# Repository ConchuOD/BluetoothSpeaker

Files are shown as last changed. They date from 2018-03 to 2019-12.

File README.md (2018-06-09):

# Teensy Bluetooth Speaker           
This repo houses the hardware and code for a bluetooth speaker. It uses an [RN52 from Roving Networks](https://www.microchip.com/wwwproducts/en/RN52) on one daughterboard to provide the bluetooth streaming capabilities and a [Teensy3.2 from PJRC](https://www.pjrc.com/store/teensy32.html) on another to control operation and power a [touchscreen display](https://www.pjrc.com/store/display_ili9341_touch.html) which displays the song metadata as well as houses AVRCP buttons.
The amplification is provided by a [TI 20 Watt Class-D amplifier](http://www.ti.com/lit/ds/symlink/tpa3140d2.pdf). Power comes from a 3S LiPo battery I had lying around from a RC project, with the amp being powered from 10.5 volts & seperate 3.3V rail for the RN52/Teensy/Display.

The V1 board only worked after a number of modifications were made. These modifications were echoed in V2 which also introduced the display. A V3 is planned which will place the RN52 directly on the board itself. As the RN52 is relatively expensive the V1/V2 boards were created with the option to use a cheap Chinese A2DP module which required swapping the ADP2370 for an adjustable version as well as inserting some zero Ohm links. An approximate BOM is included as a spreadsheet, however the pricing in the first section is all rather approximate.

*>insert photos of display, board & enclosure when complete*

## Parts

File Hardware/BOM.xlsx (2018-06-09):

Item | Part Name | Acq.? | Farnell ID | Farnell Cost | Digikey ID | Digikey Cost | OSH Park ID | OSH Park Cost | AliExpress Link | AliExpress Cost | Other ID | Other Cost | Quantity | Total Cost
Main parts
RN52 | RN52-I/RM116 | ✓ | 2491389 | €17.50 |  |  |  |  |  |  |  |  | 1 | €17.50
RN52 Shenzen | BLK-MD-SPK-B |  |  |  |  |  |  |  |  | €5.00
HC05 | HC-05 | ✓ |  |  |  |  |  |  |  | €2.95 |  |  | 1 | €2.95
T3.2 | Teensy 3.2 | ✓ |  |  |  |  |  |  |  |  | T3.2 | €19.75 | 1 | €19.75
TFT | PJRC TFT | ✓ |  |  |  |  |  |  |  |  | TFT | €10.00 | 1 | €10.00
Audio PA | TPA3140D2PWP | ✓ | 2483133 | €3.93 |  |  |  |  |  |  |  |  | 1 | €3.93
Buck Converter | ADP2370 | ✓ | 2727509 | €3.80 |  |  |  |  |  |  |  |  | 1 | €3.80
LDR | NCP59302DSADJR4G | ✓ | 2464250 | €2.81 |  |  |  |  |  |  |  |  | 1 | €2.81
RN52 BoB | n/a | ✓ |  |  |  |  | RN52BoB | $4.50 |  |  |  |  | 1 | €5.00
Main PCB | n/a | ✓ |  |  |  |  |  |  |  |  |  |  | 1 | €5.00
Enclosure |  |  |  |  |  |  |  |  | Enclosure 7.87" X 4.72" X 2.95" |  |  |  | 1 | €5.00
Li-Po Battery | ZIPPY Compact 5800mAh 3S 25C | ✓ |  |  |  |  |  |  |  |  |  | €38.00
XT-60 Female |  | ✓ |  |  |  |  |  |  |  |  | XT-60 F | ?
Speakers | Aiyima 2Pcs 8 Ohm 10W | ✓ |  |  |  |  |  |  |  | €12.60 | *hopefully* | €5.00 | 2 | €25.20 | €100.94 | €53.49
RN52 Hookup
Green LED 0603 | SML-D12P8WT86C | ✓ | 2687486 | €0.45 |  |  |  |  |  |  |  |  | 1 | €0.45
Red LED 0603 | SML-D12V8WT86C | ✓ | 2687488 | €0.45 |  |  |  |  |  |  |  |  | 1 | €0.45
330R 0603 | CRGS0603J330R | ✓ | 2531684 | €0.14 |  |  |  |  |  |  |  |  | 2 | €0.28
20 pin 0.1" Header Male | M20-9992046 | ✓ | 1022262 | €0.41 |  |  |  |  |  |  |  |  | 2 | €0.82
20 pin 0.1" Header Female | 2212S-20SG-85 | ✓ | 1593469 | €0.75 |  |  |  |  |  |  |  |  | 2 | €1.50 | €3.49
PA Hookup
100 uF Radial Can | EEEFK1C101P | ✓ | 9695672 | €0.28 |  |  |  |  |  |  |  |  | 1 | €0.28
1 uF 0603 | MC0603X105K100CT | ✓ | 1759399 | €0.23 |  |  |  |  |  |  |  |  | 10 | €2.29
220 nF 0603 | MC0603B224K160CT | ✓ | 2627437 | €0.03 |  |  |  |  |  |  |  |  | 4
100 nF 0603 | MCT0603F104ZCT | ✓ | 9406204 | €0.01 |  |  |  |  |  |  |  |  | 1
1 nF 0603 | MC0603B102K250CT | ✓ | 2627426 | €0.01 |  |  |  |  |  |  |  |  | 5
Ferrite Bead | 742792031 | ✓ | 1635734 | €0.26 |  |  |  |  |  |  |  |  | 4 | €1.04
10R 0603 | CRCW060310R0JNEAHP | ✓ | 2614306 | €0.15 |  |  |  |  |  |  |  |  | 1
39k 0603 | CRGS0603J39K | ✓ | 2531713 | €0.14 |  |  |  |  |  |  |  |  | 1
33k 0603 | CRGS0603J33K | ✓ | 2531712 | €0.14 |  |  |  |  |  |  |  |  | 3
56k 0603 | CRGS0603J56K | ✓ | 2531715 | €0.14 |  |  |  |  |  |  |  |  | 1
2 Hole Terminal Block | 1776275-2 | ✓ | 1098611 | €0.24 |  |  |  |  |  |  |  |  | 2 | €0.48 | €4.09
LDO Hookup
100 uF Radial Can | EEEFK1C101P | ✓ | 9695672 | €0.28 |  |  |  |  |  |  |  |  | 1 | €0.28
10 nF 0603 X5R | C1005X5R1E103K050BA | ✓ | 2525020 | €0.05 |  |  |  |  |  |  |  |  | 1 | €0.05
360k 0603 | ERJPA3F3603V | ✓ | 2335905 | €0.09 |  |  |  |  |  |  |  |  | 1
48k 0603 | CRGS0603J47K | ✓ | 2531714 | €0.14 |  |  |  |  |  |  |  |  | 1 |  | €0.33
Buck Conv. Hookup
10 uF 1206 X5R (output) | C1206C106K4PACTU | ✓ | 9227881 | €0.19 |  |  |  |  |  |  |  |  | 2 | €0.38
10 uF 1206 X5R (input) | MC1206X106K250CT | ✓ | 2320887 | €0.21 |  |  |  |  |  |  |  |  | 1 | €0.21
10 uH | SRN3015-100M | ✓ | 2061634 | €0.32 |  |  |  |  |  |  |  |  | 1 | €0.32
10k 0603 | CRGS0603J10K | ✓ | 2531704 | €0.14 |  |  |  |  |  |  |  |  | 1
33k 0603 | CRGS0603J33K | ✓ | 2531712 | €0.14 |  |  |  |  |  |  |  |  | 1
56K 0603 | CRGS0603J56K | ✓ | 2531715 | €0.14 |  |  |  |  |  |  |  |  | 1
68k 0603 | CRGS0603J68K | ✓ | 2531716 | €0.14 |  |  |  |  |  |  |  |  | 1
200k 0603 | ERJPA3F2053V | ✓ | 2561864 | €0.16 |  |  |  |  |  |  |  |  | 1 |  | €0.91
T3.2 Hookup
14 Pin 0.1" Header Female | 2212S-14SG-85 | ✓ | 1593466 | €0.51 |  |  |  |  |  |  |  |  | 2 | €1.02
14 Pin 0.1" Header Male | MC34735 | ✓ | 1593421 | €0.15 |  |  |  |  |  |  | PJRC | €0.85 | 2 | €1.70 | €1.70
 | HC05 Hookup
6 Pin 90degree Header | Need spacing info after delivery | ** | ** | ** | ** | ** | ** | ** | ** | ** | ** | ** | 1 | €1.50 | €1.50
 |  |  |  |  |  |  |  |  |  |  |  |  |  |  | €112.97 | €65.52

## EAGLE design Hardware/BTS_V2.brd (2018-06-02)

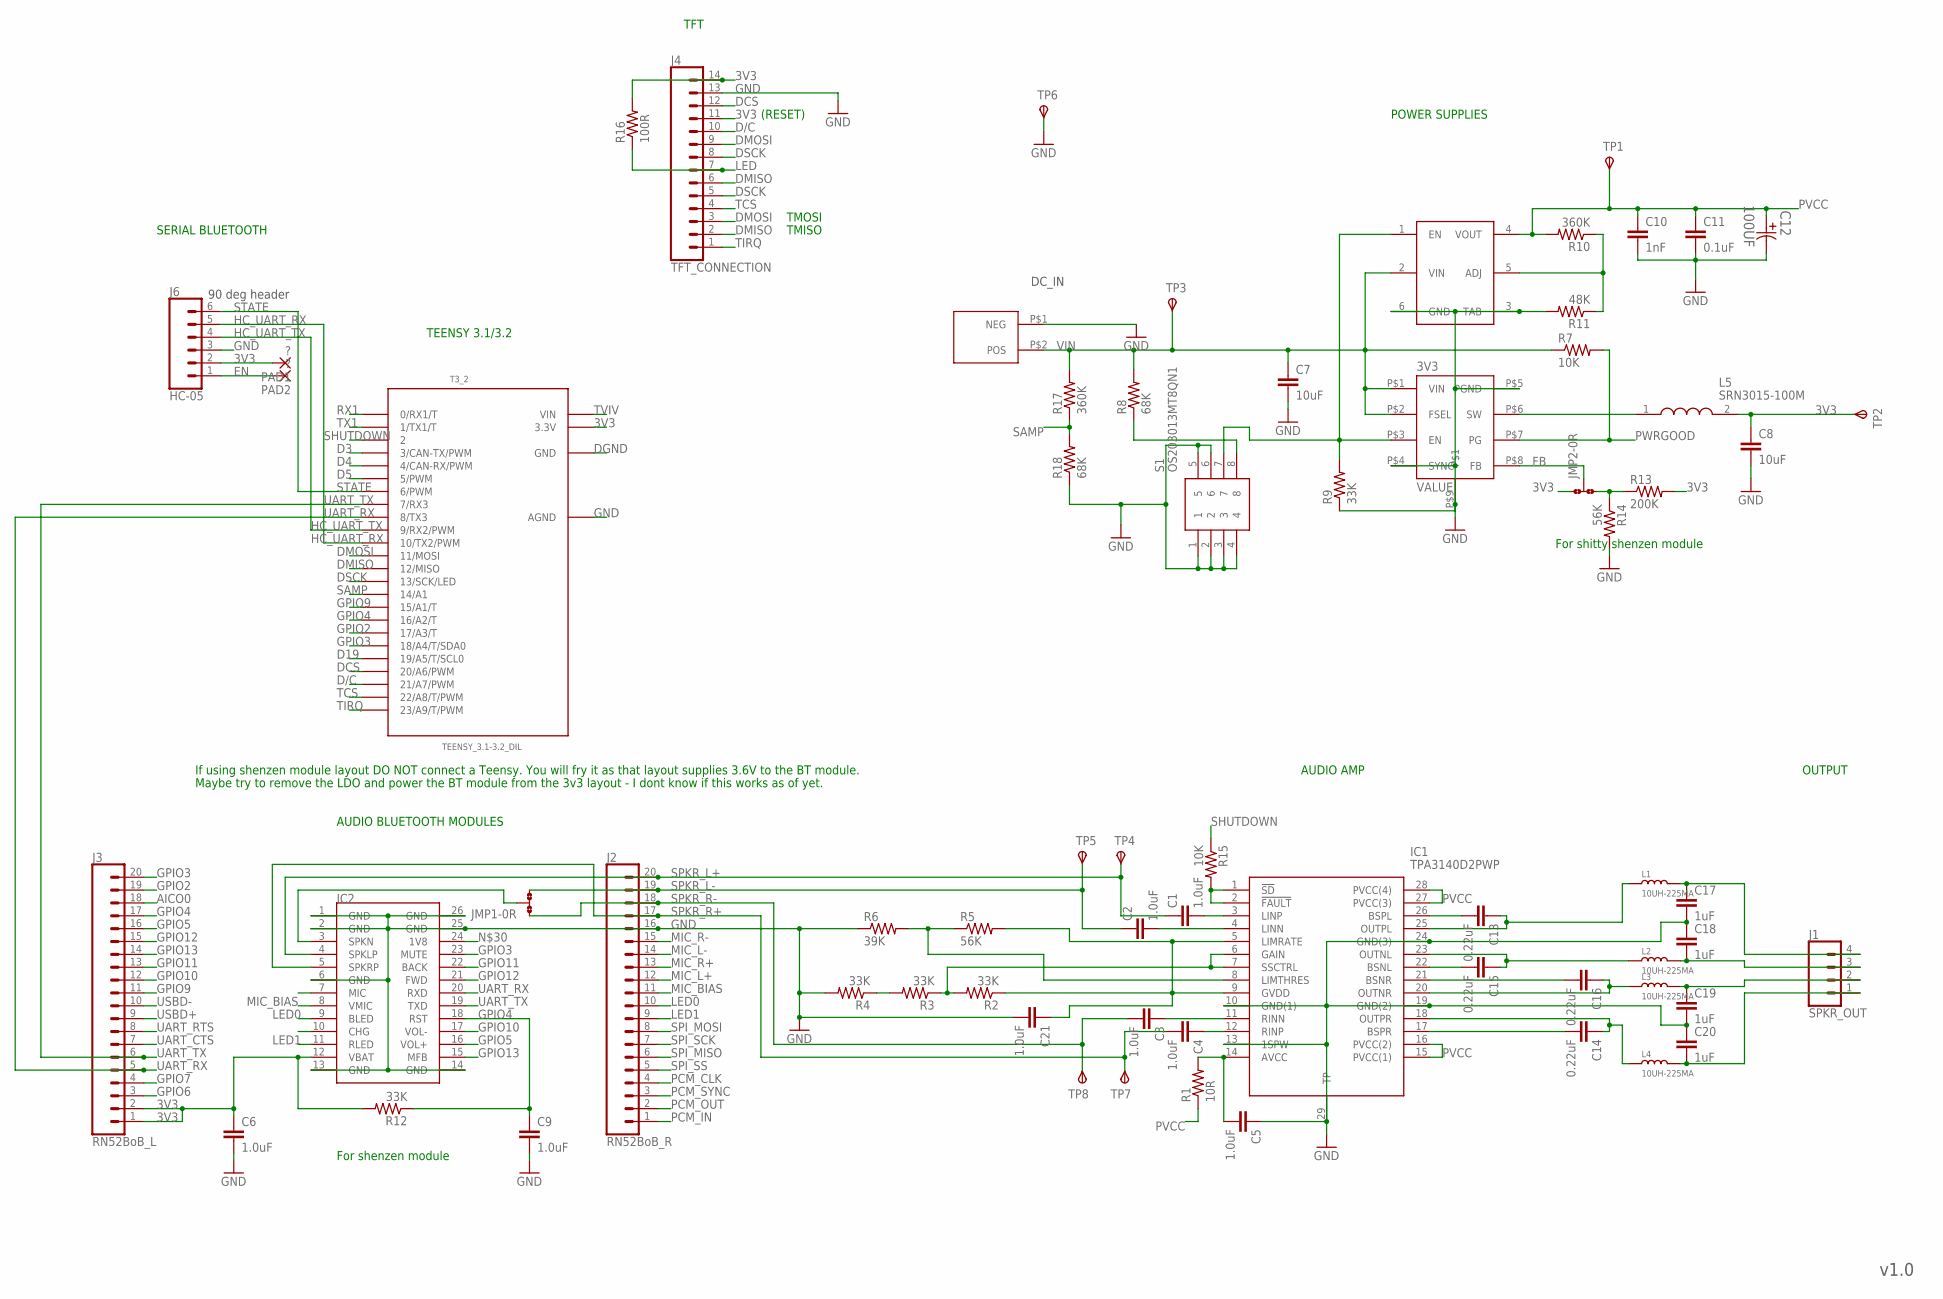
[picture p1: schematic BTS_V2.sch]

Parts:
3V3: ADP2370; 3MM_LFCSP_QFN
C1, C2, C3, C4, C5, C6, C9, C21: 1.0uF; 0603
C7, C8: 10uF; C3216
C10: 1nF; 0603
C11: 0.1uF; 0603
C12: 100UF; CAPAE660X610N
C13, C14, C15, C16: 0.22uF; 0603
C17, C18, C19, C20: 1uF; 0603
IC1: TPA3140D2PWP; SOP65P640X120-29N
IC2: BLK-MD-SPK-B
J1: SPKR_OUT; SCREWTERMINAL-3.5MM-4
J2: RN52BoB_R; 1X20
J3: RN52BoB_L; 1X20
J4: TFT_CONNECTION; 1X14
J6: HC-05; 1X06
JMP1, JMP2: 0R-JUMPA; A0R-JMP
L1, L2, L3, L4: 10UH-225MA; L0806
L5: SRN3015-100M; SRN3015
PAD1, PAD2: ?; SMD1,27-2,54
R1: 10R; R0603
R2, R3, R4, R9, R12: 33K; R0603
R5, R14: 56K; R0603
R6: 39K; R0603
R7, R15: 10K; R0603
R8, R18: 68K; R0603
R10, R17: 360K; R0603
R11: 48K; R0603
R13: 200K; R0603
R16: 100R; R0603
S1: OS203013MT8QN1
T3_2: TEENSY_3.1-3.2_DIL; TEENSY_3.0-3.2&LC_DIL
TP1, TP2, TP3, TP4, TP5, TP6, TP7, TP8: TPSPAD1-17; P1-17
U$1: HK_XT-60; HOBBYKING_XT-60
U$2: NCP59302; D2PAK-5

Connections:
3V3: C6.1, C8.1, IC2.12 (VBAT), J3.1, J3.2, J4.11, J4.14, J6.2, JMP2.1, L5.2, PAD1.1, R12.2, R13.2, R16.2, T3_2.3.3V, TP2.TP
AICO0: J3.18
BSNL: C15.2, IC1.22 (BSNL)
BSNR: C16.2, IC1.21 (BSNR)
BSPL: C13.2, IC1.26 (BSPL)
BSPR: C14.2, IC1.17 (BSPR)
D3: T3_2.3 (3/CAN-TX/PWM)
D4: T3_2.4 (4/CAN-RX/PWM)
D5: T3_2.5 (5/PWM)
D19: T3_2.19/A5 (19/A5/T/SCL0)
D/C: J4.10, T3_2.21/A7 (21/A7/PWM)
DCS: J4.12, T3_2.20/A6 (20/A6/PWM)
DGND: T3_2.GND
DMISO: J4.2, J4.6, T3_2.12 (12/MISO)
DMOSI: J4.3, J4.9, T3_2.11 (11/MOSI)
DSCK: J4.5, J4.8, T3_2.13 (13/SCK/LED)
EN: J6.1, PAD2.1
FB: 3V3.P$8 (FB), JMP2.2
GAIN: IC1.6 (GAIN), IC1.7 (SSCTRL), R2.2, R3.1
GND: 3V3.P$4 (SYNC), 3V3.P$5 (PGND), 3V3.P$9, C5.1, C6.2, C7.2, C8.2, C9.2, C10.2, C11.2, C12.2, C17.2, C18.1, C19.2, C20.1, C21.2, IC1.10 (GND(1)), IC1.13 (1SPW), IC1.19 (GND(2)), IC1.24 (GND(3)), IC1.29 (TP), IC2.1 (GND), IC2.2 (GND), IC2.6 (GND), IC2.13 (GND), IC2.14 (GND), IC2.25 (GND), IC2.26 (GND), J2.16, J4.13, J6.3, R4.2, R6.1, R9.1, R11.2, R14.2, R18.1, S1.1, S1.2, S1.3, S1.4, S1.5, S1.6, T3_2.AGND, TP6.TP, U$1.P$1 (NEG), U$2.3 (TAB), U$2.6 (GND)
GPIO2: J3.19, T3_2.17/A3 (17/A3/T)
GPIO3: IC2.23 (MUTE), J3.20, T3_2.18/A4 (18/A4/T/SDA0)
GPIO4: C9.1, IC2.18 (RST), J3.17, R12.1, T3_2.16/A2 (16/A2/T)
GPIO5: IC2.16 (VOL+), J3.16
GPIO6: J3.3
GPIO7: J3.4
GPIO9: J3.11, T3_2.15/A1 (15/A1/T)
GPIO10: IC2.17 (VOL-), J3.12
GPIO11: IC2.22 (BACK), J3.13
GPIO12: IC2.21 (FWD), J3.15
GPIO13: IC2.15 (MFB), J3.14
GVDD: C21.1, IC1.5 (LIMRATE), IC1.9 (GVDD), R2.1, R5.2
HC_UART_RX: J6.5, T3_2.10 (10/TX2/PWM)
HC_UART_TX: J6.4, T3_2.9 (9/RX2/PWM)
LED: J4.7, R16.1
LED0: IC2.9 (BLED), J2.10
LED1: IC2.11 (RLED), J2.9
LIMTHRES: IC1.8 (LIMTHRES), R5.1, R6.2
LINN: C2.2, IC1.4 (LINN)
LINP: C1.2, IC1.3 (LINP)
MIC_BIAS: IC2.8 (VMIC), J2.11
MIC_L+: J2.12
MIC_L-: J2.14
MIC_R+: J2.13
MIC_R-: J2.15
unnamed: C5.2, IC1.14 (AVCC), R1.2
unnamed: IC1.1 (!SD), IC1.2 (!FAULT), R15.2
unnamed: R3.2, R4.1
unnamed: C17.1, J1.4, L1.2
unnamed: C18.2, J1.3, L2.2
unnamed: C19.1, J1.2, L3.2
unnamed: C20.2, J1.1, L4.2
unnamed: JMP2.3, R13.1, R14.1
unnamed: IC2.3 (SPKN), JMP1.2
unnamed: 3V3.P$3 (EN), R9.2, S1.7, U$2.1 (EN)
unnamed: 3V3.P$6 (SW), L5.1
unnamed: R8.1, S1.8
unnamed: R10.1, R11.1, U$2.5 (ADJ)
OUTNL: C15.1, IC1.23 (OUTNL), L2.1
OUTNR: C16.1, IC1.20 (OUTNR), L3.1
OUTPL: C13.1, IC1.25 (OUTPL), L1.1
OUTPR: C14.1, IC1.18 (OUTPR), L4.1
PCM_CLK: J2.4
PCM_IN: J2.1
PCM_OUT: J2.2
PCM_SYNC: J2.3
PVCC: C10.1, C11.1, C12.1, IC1.15 (PVCC(1)), IC1.16 (PVCC(2)), IC1.27 (PVCC(3)), IC1.28 (PVCC(4)), R1.1, R10.2, TP1.TP, U$2.4 (VOUT)
PWRGOOD: 3V3.P$7 (PG), R7.2
RINN: C3.1, IC1.11 (RINN)
RINP: C4.1, IC1.12 (RINP)
RX1: T3_2.0 (0/RX1/T)
SAMP: R17.1, R18.2, T3_2.14/A0 (14/A1)
SHUTDOWN: R15.1, T3_2.2
SPI_MISO: J2.6
SPI_MOSI: J2.8
SPI_SCK: J2.7
SPI_SS: J2.5
SPKR_L+: C1.1, IC2.4 (SPKLP), J2.20, TP4.TP
SPKR_L-: C2.1, J2.19, JMP1.3, TP5.TP
SPKR_R+: C4.2, IC2.5 (SPKRP), J2.17, TP7.TP
SPKR_R-: C3.2, J2.18, JMP1.1, TP8.TP
STATE: J6.6, T3_2.6 (6/PWM)
TCS: J4.4, T3_2.22/A8 (22/A8/T/PWM)
TIRQ: J4.1, T3_2.23/A9 (23/A9/T/PWM)
TVIV: T3_2.VIN
TX1: T3_2.1 (1/TX1/T)
UART_CTS: J3.7
UART_RTS: J3.8
UART_RX: IC2.20 (RXD), J3.5, T3_2.8 (8/TX3)
UART_TX: IC2.19 (TXD), J3.6, T3_2.7 (7/RX3)
USBD+: J3.9
USBD-: J3.10
VIN: 3V3.P$1 (VIN), 3V3.P$2 (FSEL), C7.1, R7.1, R8.2, R17.2, TP3.TP, U$1.P$2 (POS), U$2.2 (VIN)

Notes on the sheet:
For shenzen module
For shitty shenzen module
DC_IN
90 deg header
If using shenzen module layout DO NOT connect a Teensy. You will fry it as that layout supplies 3.6V to the BT module.
v1.0
(RESET)
TMOSI
TMISO
Maybe try to remove the LDO and power the BT module from the 3v3 layout - I dont know if this works as of yet.
TFT
POWER SUPPLIES
AUDIO AMP
OUTPUT
AUDIO BLUETOOTH MODULES
SERIAL BLUETOOTH
TEENSY 3.1/3.2

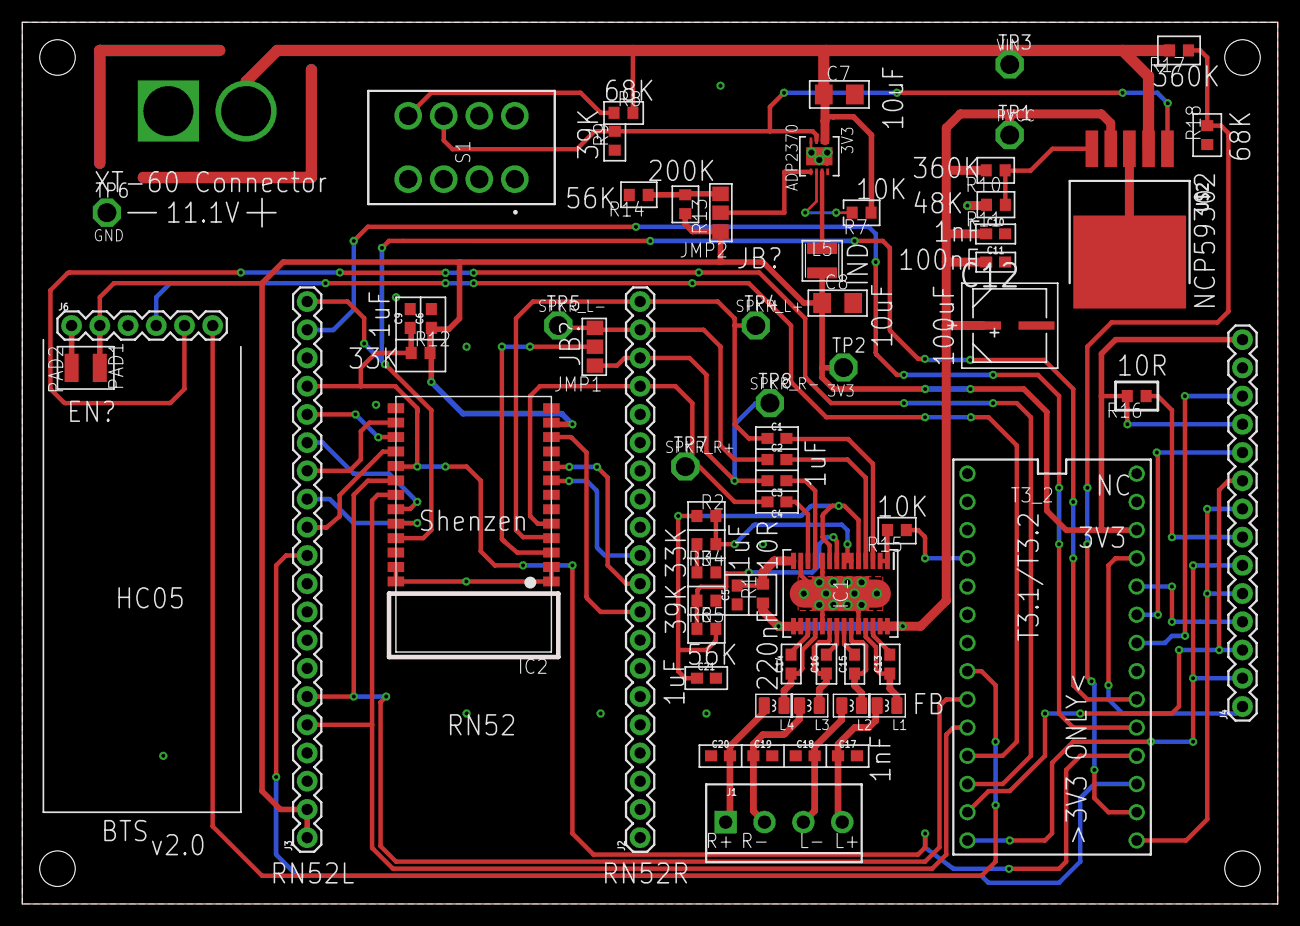
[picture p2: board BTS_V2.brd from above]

Board: 2 copper layers, 113.0 x 79.4 mm, 68 parts (0 on the bottom side), 66 nets.

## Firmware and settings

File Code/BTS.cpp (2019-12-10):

/* Optional code segments - using this to seperately test code segments */

//#define DEBUG 1
#define DISPLAY 1
//define HC05 1

/* Requried libraries */
#include <HardwareSerial.h>
#include <ILI9341_t3.h>
#include <font_DroidSansMono.h>
#include <RN52_HardwareSerial.h>
#include <WString.h>
#include <XPT2046_Touchscreen.h>

/* Buttons for the screen */
#include "Pictures.h"

/* Definitions */
#define TFT_DC      21
#define TFT_CS      20
#define TFT_RST     255  // 255 = unused, connect to 3.3V
#define TFT_MOSI    11
#define TFT_SCLK    13
#define TFT_MISO    12
#define TOUCH_CS    22
#define TOUCH_IRQ   23
#define TS_MINX     300
#define TS_MINY     220
#define TS_MAXX     4000
#define TS_MAXY     3900
#define SERIAL_BAUD_RATE    115200
#define RN52_BAUD_RATE      115200
#define BUTTON_HEIGHT       60
#define BUTTON_WIDTH        64
#define METADATA_RESET      100
#define GPIO2_PIN           17
#define GPIO9_PIN           15
#define PIN_SHUTDOWN        2
#define PIN_SENSE           14
#define LOW_VOLTAGE_CUTOFF  488 //3.3*3 (battery) *68/420 (sense) *1024/3.3 (ADC)
#define STRING_DISP_LIMIT   17
#define TEXT_COLOUR CL(96,96,96)


/* Globals */
#ifdef DISPLAY
ILI9341_t3 TFT = ILI9341_t3(TFT_CS, TFT_DC, TFT_RST, TFT_MOSI, TFT_SCLK, TFT_MISO);
XPT2046_Touchscreen TouchScreen(TOUCH_CS, TOUCH_IRQ);
#endif

/* Function delarations */
void shutdown(void); //write this function

/** Finish Metadata related AT commands in HWSerial before using **/
int main(void){
    /* Variables */
    #ifdef DEBUG
    int timer = 0;
    #endif
    char c, time_out[12] = "", previous_time_out[12] = "";
    String song_artist = "", song_album = "", song_title = "";
    String previous_album = "", previous_title = "", previous_artist = "";
    int song_duration = 0;
    int start_time = 0, elapsed_time = 0;
    int duration_seconds = 0, duration_minutes = 0;
    int elapsed_seconds = 0, elapsed_minutes = 0;
    uint16_t event_reg_status = 0, paused_event_mask = 0b00000010, new_event_mask = 0b0000100000000000;
    TS_Point touched_location;
    uint8_t touched_flag_array = 0;
    bool new_song_flag = false, GPIO_2_status = true;
    uint8_t paused_flag_array = 0, paused_flag_mask = 3;
    /* Setup code */
    sei();  //enable interupts
    pinMode(GPIO9_PIN, OUTPUT);    //pin for command mode
    digitalWrite(GPIO9_PIN, HIGH);
    pinMode(GPIO2_PIN, INPUT); //pin for event register
    pinMode(PIN_SENSE, INPUT);    //pin for low voltage cutoff
    pinMode(PIN_SHUTDOWN, OUTPUT);  //pin for PA enable
    digitalWrite(PIN_SHUTDOWN, LOW);
    delay(1000);    //wait before setup
    #ifdef DEBUG
    Serial.begin(SERIAL_BAUD_RATE); //enable USB serial for tests
    while (!Serial){}
    Serial.println("Starting HC05 Serial");
    #endif
    #ifdef HC05
    Serial2.begin(SERIAL_BAUD_RATE);    //enable HC05
    #endif
    RN52_Serial3.begin(RN52_BAUD_RATE); //enable RN52
    #ifdef DEBUG
    Serial.println("Starting RN52 Serial");
    #endif
    digitalWrite(GPIO9_PIN, LOW);
    while (RN52_Serial3.available() == 0);   //wait for ACK (CMD)
    c = RN52_Serial3.read();
    if (c == 'C'){
        delay(100);
        RN52_Serial3.flush();
        #ifdef DEBUG
        Serial.println("Successfully entered command mode.");
        #endif
    }
    /* Turn on track change event */
    RN52_Serial3.trackChangeEvent(1);   
    #ifdef DEBUG
    Serial.print("Ext. features: ");
    Serial.println(RN52_Serial3.getExtFeatures());
    #endif
    #ifdef DISPLAY
    /* Setup the buttons on the display */
    TFT.begin();    //returns void
    #ifdef DEBUG
    Serial.println("Started display");
    #endif
    if(!TouchScreen.begin()){
        #ifdef DEBUG
        Serial.println("Failed to start touchscreen.");
        #endif
    }
    delay(1000); 
    TFT.fillScreen(ILI9341_BLACK);
    TFT.setTextColor(TEXT_COLOUR);
    TFT.setTextSize(2);
    TFT.setFont(DroidSansMono_16);
    TFT.setRotation(3);
    TouchScreen.setRotation(1);
    /** 
        Later these can be made into bitmaps of actual buttons?
    **/
    TFT.writeRect(0,180,BUTTON_WIDTH,BUTTON_HEIGHT,(uint16_t*) MinusButton);        //vol down
    TFT.writeRect(64,180,BUTTON_WIDTH,BUTTON_HEIGHT,(uint16_t*) PreviousButton);      //previous
    TFT.writeRect(128,180,BUTTON_WIDTH,BUTTON_HEIGHT,(uint16_t*) PauseButton);       //play/pause
    TFT.writeRect(192,180,BUTTON_WIDTH,BUTTON_HEIGHT,(uint16_t*) NextButton);    //next
    TFT.writeRect(256,180,BUTTON_WIDTH,BUTTON_HEIGHT,(uint16_t*) PlusButton);  //vol up
    /* Initialise the song display */
    TFT.setCursor(10,4);
    TFT.print(" Title:");
    TFT.setCursor(10,48);
    TFT.print("Artist:");
    TFT.setCursor(10,92);
    TFT.print(" Album:");
    TFT.setCursor(10,136);
    TFT.print("  Time:");
    TFT.setCursor(100,4);
    #endif
    digitalWrite(PIN_SHUTDOWN, HIGH); // turn on PA after setup complete
    /* Operational code */
    for(;;){
        if(analogRead(PIN_SENSE) < 488){
            TFT.fillScreen(ILI9341_BLACK);
            TFT.setCursor(10,4);
            TFT.print("LVC SHUTDOWN");
            TFT.setCursor(10,48);
            TFT.print("CHARGE BATTERY TO CONTINUE");
            shutdown();
        }
        #ifdef DEBUG
        delay(50);
        timer = millis();
        #endif
        #ifdef DISPLAY
        touched_flag_array |= (bool) TouchScreen.touched();
        if(touched_flag_array & 0b1){
            if(!(touched_flag_array & 0b11111110)){
                touched_location = TouchScreen.getPoint(); 


                #ifdef DEBUG
                Serial.print("X coord =");
                Serial.println(touched_location.x);
                Serial.print("Y coord =");
                Serial.println(touched_location.y);
                #endif
                if(touched_location.x < 960 && touched_location.y > 2900){
                    RN52_Serial3.volumeDown();
                    #ifdef DEBUG
                    Serial.println("Volume decreased.");
                    #endif
                }
                else if(touched_location.x < 1720 && touched_location.y > 2900){
                    RN52_Serial3.prevTrack();    //previous
                    new_song_flag = true;
                    paused_flag_array |= false;;
                    #ifdef DEBUG
                    Serial.println("Song rewound.");
                    #endif
                }
                else if(touched_location.x < 2480 && touched_location.y > 2900){
                    RN52_Serial3.playPause();    //pause
                    paused_flag_array |= ((paused_flag_array >> 1) & 0b1) ? false : true; //toggle paused flag
                    #ifdef DEBUG
                    Serial.println("Paused.");
                    #endif
                }
                else if(touched_location.x < 3240 && touched_location.y > 2900){
                    RN52_Serial3.nextTrack();    //skip
                    new_song_flag = true;
                    paused_flag_array |= false;;
                    #ifdef DEBUG
                    Serial.println("Song skipped.");
                    #endif
                }
                else if(touched_location.x > 3240){
                    RN52_Serial3.volumeUp();    //volUp
                    #ifdef DEBUG
                    Serial.println("Volume increased.");
                    #endif    
                }           
            }
        }
        #endif
        #ifdef HC05
        /* Check for HC05 commands */
        if(Serial2.available() != 0){
            c = Serial2.read();
            switch(c){
                case ' ':
                    RN52_Serial3.playPause();    //pause
                    paused_flag = paused_flag ? false : true; //toggle paused flag
                    #ifdef DEBUG
                    Serial.println("Paused.");
                    #endif
                    break;
                case '+':
                    RN52_Serial3.volumeUp();    //volUp
                    #ifdef DEBUG
                    Serial.println("Volume increased.");
                    #endif
                    break;
                case '-':
                    RN52_Serial3.volumeDown();    //volDown
                    #ifdef DEBUG
                    Serial.println("Volume decreased.");
                    #endif
                    break;
                case '>':
                    RN52_Serial3.nextTrack();    //skip
                    new_song_flag = true;
                    paused_flag_array |= false;;
                    #ifdef DEBUG
                    Serial.println("Song skipped.");
                    #endif
                    break;
                case '<':
                    RN52_Serial3.prevTrack();    //previous
                    new_song_flag = true;
                    paused_flag_array |= false;;
                    #ifdef DEBUG
                    Serial.println("Song rewound.");
                    #endif
                    break;
                default:
                    #ifdef DEBUG
                    Serial.println("Another button was pressed.");
                    #endif
            }   
        }
        #endif
        /* Check bit 5 of the status register to see if there has been a new song */
        GPIO_2_status = digitalRead(GPIO2_PIN);
        if(!GPIO_2_status){
            event_reg_status = RN52_Serial3.queryState();
            #ifdef DEBUG
            Serial.print("event_reg_status ");
            Serial.println(event_reg_status);
            #endif
            if((event_reg_status & new_event_mask) >> 11){
                new_song_flag = true;
                #ifdef DEBUG
                Serial.print("track event ");
                #endif 
            }
            if((event_reg_status & paused_event_mask) >> 1){
                paused_flag_array |= true;;
                #ifdef DEBUG
                Serial.println("Paused");
                #endif 
            }
            else{
                paused_flag_array |= false;;
                #ifdef DEBUG
                Serial.println("Un-paused");
                #endif 
            }
        }
        /** 
            Do some maths here in an attempt to detect if a new song is possible, if it is set the new_song_flag.
            Maybe: start time + elasped > duration.
            On second thoughts, do I need this?
        **/
        /* Now get metadata information */
        if( (strcmp(time_out, "") == 0) || millis()%METADATA_RESET == 0 || new_song_flag){  //runs on startup, every n seconds and on changes 
            RN52_Serial3.getMetaData();
            previous_album = song_album;  //save the old versions of the text so that we can wipe screen
            song_album = RN52_Serial3.album();
            song_album.remove(STRING_DISP_LIMIT);
            previous_title = song_title;
            song_title = RN52_Serial3.trackTitle();  
            song_title.remove(STRING_DISP_LIMIT);
            previous_artist = song_artist;            
            song_artist = RN52_Serial3.artist();  
            song_artist.remove(STRING_DISP_LIMIT);
            song_duration = RN52_Serial3.trackDuration();  

            if(song_title == "" || song_artist == ""){
                new_song_flag = false; 
                continue;  //if info is blank then we have no song playing.
            }
            else if (song_title != previous_title){
                new_song_flag = true;
            } 
        }
        //if(new_song_flag && paused_flag){
        //    new_song_flag = false;  /** workaround, think no longer required? **/
        //}
        /* Time update */
        if(new_song_flag){
            start_time = millis();
            #ifdef DEBUG          
            Serial.print("Title: ");
            Serial.println(song_title);
            #endif
        }
        duration_seconds = (song_duration/1000)%60;
        duration_minutes = ((song_duration/1000)/60)%60;
//        paused_flag_array |= paused_flag;
        switch(paused_flag_array){
            case 0:  //keep increasing elapsed time
                elapsed_time = millis() - start_time;
                break;                
            case 1:  //play button
                TFT.writeRect(128,180,BUTTON_WIDTH,BUTTON_HEIGHT,(uint16_t*) PlayButton);
                break;                
            case 2:  //compute new start time
                start_time = millis() - elapsed_time;  //lol bodged
                TFT.writeRect(128,180,BUTTON_WIDTH,BUTTON_HEIGHT,(uint16_t*) PauseButton);       //play/pause
                break;                
            case 3:  //still paused
                break;
            default:
                shutdown();
                #ifdef DEBUG
                Serial.println("Error");
                #endif
        }        
        elapsed_seconds = (elapsed_time/1000)%60;
        elapsed_minutes = ((elapsed_time/1000)/60)%60;
        strcpy(previous_time_out,time_out);
        sprintf(time_out,"%02d:%02d/%02d:%02d", elapsed_minutes, elapsed_seconds, duration_minutes, duration_seconds);
        #ifdef DISPLAY
        if(strcmp(previous_time_out,time_out) != 0){ /** modify to only update the changed character **/
            TFT.setTextColor(ILI9341_BLACK);        
            TFT.setCursor(100,136);
            TFT.print(previous_time_out); //print the old time in black
            TFT.setTextColor(TEXT_COLOUR);
            TFT.setCursor(100,136);
            TFT.print(time_out); //print the new time
        }
        /* Metadata Update */
        if(new_song_flag){
            TFT.setTextColor(ILI9341_BLACK);
            TFT.setCursor(100,4);
            TFT.print("?");
            TFT.setCursor(100,4);
            TFT.print(previous_title);
            TFT.setCursor(100,48);
            TFT.print(previous_artist);
            TFT.setCursor(100,92);
            TFT.print("?");
            TFT.setCursor(100,92);
            TFT.print(previous_album);            
            TFT.setTextColor(TEXT_COLOUR);
            TFT.setCursor(100,4);
            TFT.print(song_title);
            TFT.setCursor(100,48);
            TFT.print(song_artist);
            TFT.setCursor(100,92);
            TFT.print(song_album);
            TFT.setCursor(100,136);
        } 
        #endif
        paused_flag_array = (paused_flag_array << 1) & paused_flag_mask;	//update previously paused flag. 
        new_song_flag = false;    //reset flags
        touched_flag_array = (touched_flag_array << 1);
        //#ifdef DEBUG
        //Serial.print("Loop time: ");
        //Serial.println(millis() - timer);
        //#endif
    }
    shutdown(); //if this is reached something really bad has happened.    
}

void shutdown(void){ // send exit cmd mode, do all shutdown stuff
    digitalWrite(PIN_SHUTDOWN, LOW); //turn off the PA
    #ifdef DEBUG
    Serial.println("-----------------------");
    Serial.println("Something bad happened.");
    Serial.println("-----------------------");
    #endif
}

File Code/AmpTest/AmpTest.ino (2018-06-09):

#include <RN52_HardwareSerial.h>
#define PIN_SHUTDOWN 2
#define MAX_AMP_ON_TIME 20000
void setup() {
    char c;
    unsigned long initTime;
    unsigned long elapsedTime;
    //RN52_Serial3 object is instantiated globally in library.
    pinMode(15, OUTPUT);
    pinMode(PIN_SHUTDOWN, OUTPUT);
    digitalWrite(15, HIGH);
    digitalWrite(PIN_SHUTDOWN, LOW);
    Serial.begin(115200);
    while (!Serial){}
    Serial.println("Ready!");
    RN52_Serial3.begin(115200);
    delay(1000);
    Serial.println("Running RN52 setup:");
    digitalWrite(15, LOW);  //drive low to init command mode
    while (RN52_Serial3.available() == 0){}  //wait for ACK (AOK\r\n or AOK\n\r, I forget which)
    Serial.println("Recieved something.");
    c = RN52_Serial3.read();
    if (c == 'C') {
       delay(100);
       RN52_Serial3.flush();
       Serial.println("Successfully entered command mode");
    }
    Serial.print("Please connect to the module and begin to play some music\n");
    while(Serial.available() == 0){}
    Serial.println("Recieved something.");
    while(Serial.available() > 0){
          c = Serial.read();
    }
    RN52_Serial3.println("S%,0001");
    Serial.println("Doing AVRCP stuff");
    RN52_Serial3.volumeUp();
    RN52_Serial3.volumeUp();
    RN52_Serial3.volumeUp();

    RN52_Serial3.getMetaData();
    Serial.println(RN52_Serial3.trackDuration());
    Serial.println("Running PA init:");
    digitalWrite(PIN_SHUTDOWN, HIGH);
    initTime = millis();
    Serial.print("Send a character when you wish to turn off the amp.\n");
    while(elapsedTime < MAX_AMP_ON_TIME){
        elapsedTime = millis() - initTime;
    }
    digitalWrite(PIN_SHUTDOWN, LOW);
    Serial.println("Amp turned off.");
}

void loop() {
  //Do nothing
}

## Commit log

2018-02-26 v1.0 for PCB fabrication
2018-02-26 tPlace additions
    [BTS.brd]
2018-03-14 Moved hardware files
    [BOM.xlsx, BTS.brd, BTS.sch]
2018-03-15 Finally fixed?
    [BOM.xlsx]
2018-03-21 XT60 connects still wrong size
    [BTS_V2.brd, BTS_V2.sch]
2018-03-21 Deleted duplicate directory
    [BTS_V2.brd, BTS_V2.sch]
2018-03-21 XT-60 connects still wrong size
    [BTS_V2.brd, BTS_V2.sch]
2018-03-26 Created new XT-60 connector
    [BTS_V2.brd, BTS_V2.sch]
2018-03-28 added PA test code & modified V2 board files
    [BTS_V2.brd, BTS_V2.sch]
2018-03-28 Readme and ARDUINO IDE required changes
2018-03-28 Further error fixed
    [BTS_V2.brd]
2018-03-28 Error actually fixed
    [BTS_V2.brd]
2018-03-30 Removed examples from SPI lib
2018-04-03 Board errors corrected
    [BTS_V2.brd, BTS_V2.sch]
2018-04-10 Still working on figuring out an error w/ the board
    [BTS.sch, BTS_V2.brd]
2018-04-10 still tracking down issue
    [BTS_V2.brd]
2018-04-22 Finally solved the issue - was a too large cap on output
    [BTS_V2.brd, BTS_V2.sch]
2018-04-26 Fixed a major and minor Makefile issues and general fixes in BTS.cpp
    [AmpTest.ino, BTS.cpp]
2018-05-03 variable names & board v2 for manuf.
    [BTS_V2.brd]
2018-05-27 Bug fixing for display
    [BTS.cpp, SFRRanger_reader.ino, Scanner.ino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]
2018-05-29 Fixed a time display bug & word overlaps
    [BTS.cpp]
2018-06-02 fixing time update code
    [BTS.cpp]
2018-06-02 Fixed two HW issues
    [BTS_V2.brd, BTS_V2.sch]
2018-06-02 Starting to use button bitmaps
2018-06-02 BITMAP BUTTONS, AYYYO
2018-06-06 removed unneeded variables. Hopefully broke nothing
    [BTS.cpp]
2018-06-07 BOM update
    [BOM.xlsx]
2019-12-10 Updating rn52 breakout to one with saved gerbers

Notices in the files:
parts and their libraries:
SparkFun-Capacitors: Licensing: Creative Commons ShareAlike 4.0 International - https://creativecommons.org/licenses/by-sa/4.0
